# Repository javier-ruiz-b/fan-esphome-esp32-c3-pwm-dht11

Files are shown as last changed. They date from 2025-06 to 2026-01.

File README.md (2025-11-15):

# ESPhome silent fan control for heaters (ESP32 c3)

Features:

* Automatic fan control depending on heater temperature
* Connected to HomeAssistant with MQTT
* All features ESPHome brings

Planned features:

* Power efficient - deep sleep
* Control override

---

Software requirements:

* Modern Python version
* ESPhome

Required hardware (Adapt to your needs):

* 4x 5V PWM fans with RPM sensing
* DHT11 temp sensor
* 5V power supply

## Circuit diagram

Ignore the ESP on the diagram, as it does not match the ESP32c3.
Use the pins specified in the esp32c3_bedroom_pwm.yaml.template.

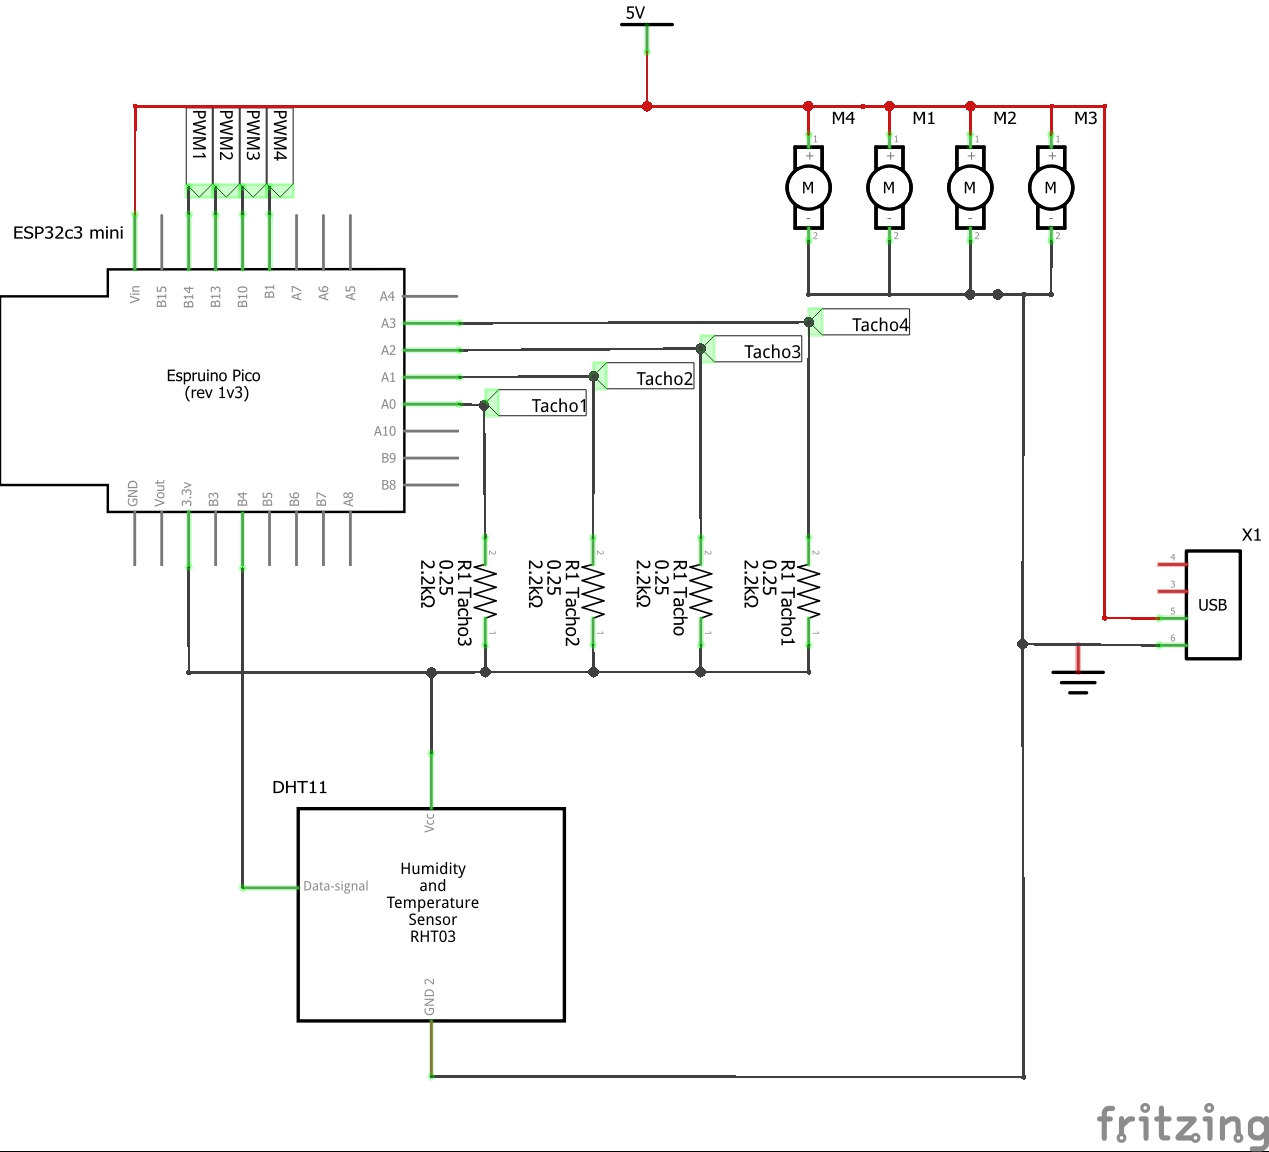
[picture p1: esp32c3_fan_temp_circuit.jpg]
ESP32C3 Fan and DHT11 Temp Sensor Circuit


## Setup development

Depending on your OS you may want to create a venv first.

```bash
pip install -r requirements.txt 
```

## Build and flash

### secrets.txt

Create a file named secrets.txt on the same root directory with these contents:

```text
WIFI_SSID=...
WIFI_PSK=...
FALLBACK_AP_SSID=...
FALLBACK_AP_PSK=...
API_KEY=...
```

### Flash

Now run `flash_bedroom.sh` to flash the ESP32 with this configuration. 

## Connection to home assistant

Follow this wizard: https://my.home-assistant.io/redirect/integration/?domain=esphome

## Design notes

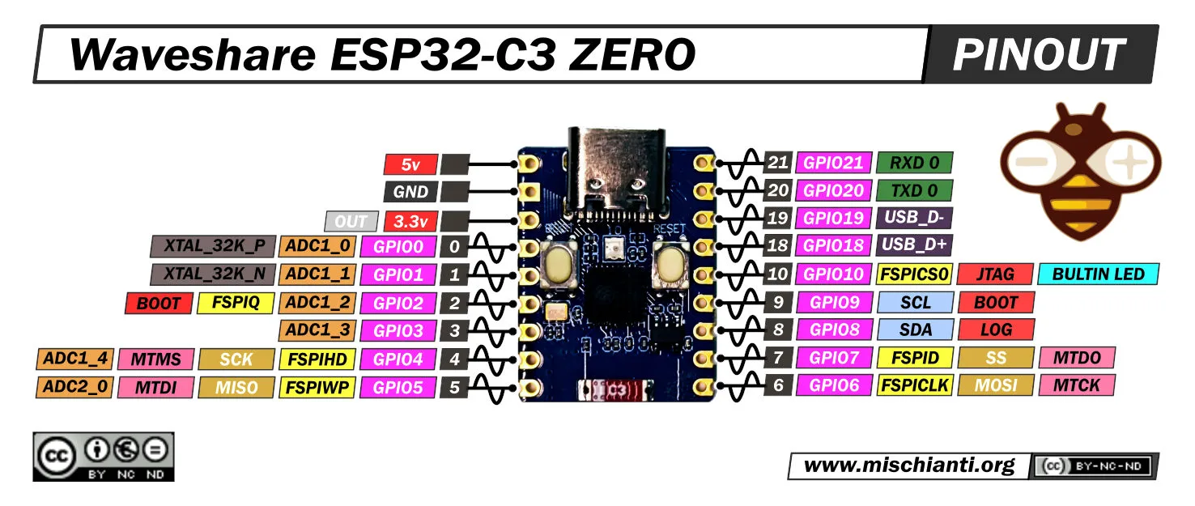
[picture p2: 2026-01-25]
hardware/ESP32-C3-ZERO-Waveshare-pinout-low.jpg.webp

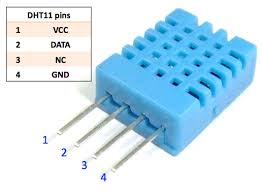
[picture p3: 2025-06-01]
hardware/DHT11.jpg

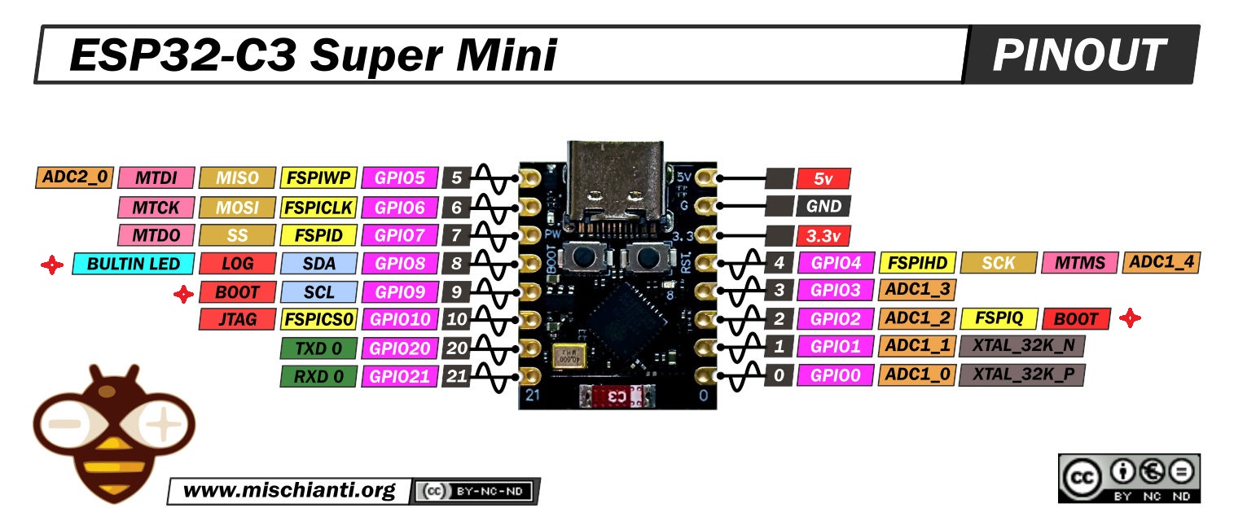
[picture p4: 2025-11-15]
hardware/ESP32-C3-Super-Mini-pinout-low.jpg

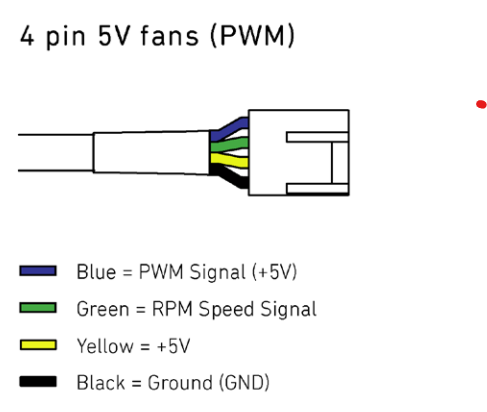
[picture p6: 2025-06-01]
hardware/Noctua pinout.png

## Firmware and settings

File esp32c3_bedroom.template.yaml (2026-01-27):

esphome:
  name: bedroom-fan
  includes:
    - interpolation.h

esp32:
  variant: ESP32C3
  board: esp32-c3-devkitm-1
  framework:
    type: esp-idf

# Enable Home Assistant API
api:
  encryption:
    key: "{{API_KEY}}="

# Enable OTA updates
ota:
  platform: esphome

# Enable WiFi (replace with your SSID and password)
wifi:
  power_save_mode: LIGHT
  output_power: 15db
  ssid: "{{WIFI_SSID}}"
  password: "{{WIFI_PSK}}"
  ap:  # Fallback AP if WiFi fails
    ssid: "{{FALLBACK_AP_SSID}}"
    password: "{{FALLBACK_AP_PSK}}"

# Logger and Web server (optional for debugging)
logger:
  level: INFO
web_server:

# PWM Outputs on GPIOs (adjust pins based on your setup)
output:
  - platform: ledc
    pin: GPIO20
    id: pwm_1
    frequency: 19531Hz
  - platform: ledc
    pin: GPIO18
    id: pwm_2
    frequency: 19531Hz
  - platform: ledc
    pin: GPIO9
    id: pwm_3
    frequency: 19531Hz
  - platform: ledc
    pin: GPIO7
    id: pwm_4
    frequency: 19531Hz

# Define the DHT11 sensor
sensor:
  - platform: dht
    id: radiator_dht11
    pin: GPIO4
    model: DHT11
    temperature:
      name: "Radiator Temperature"
      id: radiator_temperature
      on_value:
        then:
          - script.execute: update_fan_speed
    humidity:
      name: "Radiator Humidity"
      id: radiator_humidity
    update_interval: 15s

  - platform: homeassistant
    name: "Heating Value"
    entity_id: sensor.schlafzimmer_heating
    id: heating
    internal: false
    on_value:
      then:
        - script.execute: update_fan_speed
    
  - platform: homeassistant
    name: "Room Temperature"
    entity_id: sensor.schlafzimmer_temperature
    id: room_temperature
    internal: false
    on_value:
      then:
        - script.execute: update_fan_speed

    

# not working
  - platform: pulse_counter 
    pin:
      number: GPIO21
      mode: INPUT_PULLUP
    unit_of_measurement: 'RPM'
    id: speed_1
    name: speed 1
    update_interval: 5s
    filters:
      - multiply: 0.5

  - platform: pulse_counter
    pin:
      number: GPIO19
      mode: INPUT_PULLUP
    unit_of_measurement: 'RPM'
    id: speed_2
    name: speed 2
    update_interval: 5s
    filters:
      - multiply: 0.5

  # not working pin
  # - platform: pulse_counter
  #   pin:
  #     number: GPIO10
  #     mode: INPUT_PULLUP
  #   unit_of_measurement: 'RPM'
  #   id: speed_3
  #   name: speed 3
  #   update_interval: 5s
  #   filters:
  #     - multiply: 0.5
      
  - platform: pulse_counter
    pin:
      number: GPIO8
      mode: INPUT_PULLUP
    unit_of_measurement: 'RPM'
    id: speed_4
    name: speed 4
    update_interval: 5s
    filters:
      - multiply: 0.5

  # - platform: mqtt_subscribe
  #   name: "Tado Heating"
  #   topic: "homeassistant/sensor/schlafzimmer_heating/state"
  #   id: heating
  #   on_value:
  #     then:
  #       - script.execute: update_fan_speed

  # - platform: mqtt_subscribe
  #   name: "Tado Window Open"
  #   topic: "homeassistant/binary_sensor/schlafzimmer_window/state"
  #   id: window
  #   on_value:
  #     then:
  #       - script.execute: update_fan_speed

binary_sensor:    
  - platform: homeassistant
    name: "Window Open"
    entity_id: binary_sensor.schlafzimmer_window
    id: window
    internal: false
    on_state:
      then:
        - script.execute: update_fan_speed

# Expose PWM controls
fan:
  - platform: speed
    output: pwm_1
    name: "Fan 1"
  - platform: speed
    output: pwm_2
    name: "Fan 2"
  - platform: speed
    output: pwm_3
    name: "Fan 3"
  - platform: speed
    output: pwm_4
    name: "Fan 4"
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

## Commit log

2025-06-01 doc: add fritzing circuit and exported PNG diagram
    [esp32c3_fan_temp.fzz]
2025-06-01 feat: read RPM from each fan. Move more variables to the secrets file.
2025-06-01 fix: corrected pin 0 and verified RPMs - pullup resistors may be removed from the diagram
2025-10-19 fix: working prototype. wifi power needs to be manually set, otherwise it would constantly lose connection
    [esp32c3_pwm.template.yaml]
2025-10-19 feat: first working prototype - sets speed based on vars
2025-10-19 fix: heating values are between 0 and 100. Adjusted temp sensor range
    [esp32c3_pwm.template.yaml]
2025-10-23 chore: replaced comments and adjusted vars
    [esp32c3_pwm.template.yaml]
2025-10-26 fix: fans would no turn off. Also adjusted and refactored temp/speed/heating params
    [esp32c3_pwm.template.yaml]
2025-11-15 feat: add livingroom circuit
    [esp32c3_bedroom_fan_temp.fzz]
2025-11-15 fix errors and adjust values
    [esp32c3_bedroom.template.yaml, esp32c3_livingroom.template.yaml]
2026-01-09 fix: linux fixes and small changes
    [esp32c3_bedroom.template.yaml]
2026-01-25 replaced the ESP for the bedroom with a Waveshare ESP32 C3 Zero - changed GPIOs to match the new microcontroller
    [esp32c3_bedroom.template.yaml, esp32c3_livingroom.template.yaml]
2026-01-25 adapted temperature values as the sensor is now inside the radiator
2026-02-27 fix: changed heating id because now using tado ce
2026-10-25 fix: removed tado sensors, keep standalone config
2026-10-25 fix: keep it running if sensor fails
